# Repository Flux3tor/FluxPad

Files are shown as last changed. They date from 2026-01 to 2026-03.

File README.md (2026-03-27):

# FluxPad

FluxPad is a custom 12-key macropad powered by the Seeed XIAO RP2040.  
It features a rotary encoder for volume and scrolling, an OLED status display, and a compact 3D-printed case designed for daily productivity and creative workflows.

---

## Features
- 12 MX mechanical keys
- Rotary encoder (volume + scroll control)
- 0.91" OLED display (layer & status display)
- Seeed XIAO RP2040 microcontroller
- QMK firmware
- Fully custom 2-layer PCB
- 3D-printed case

---

## Project Images

### Schematic
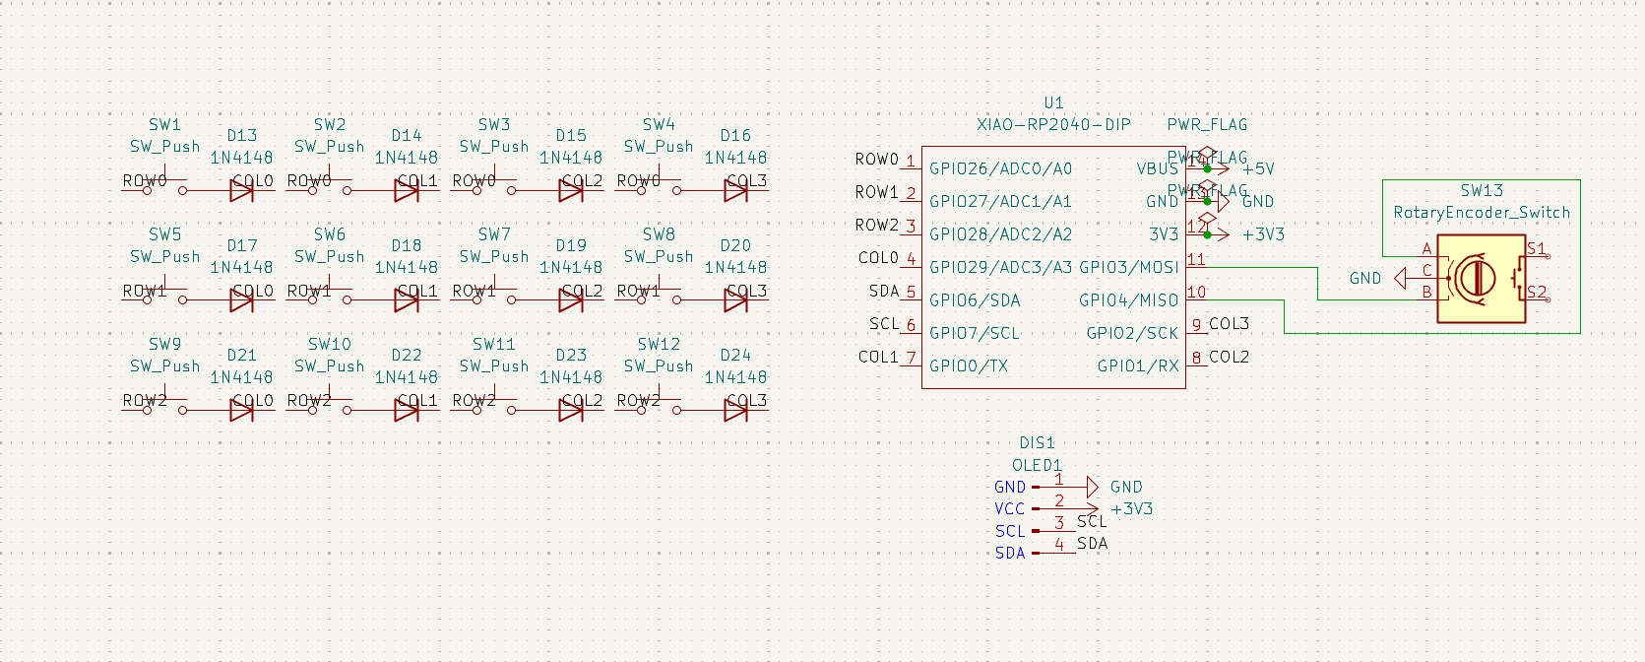
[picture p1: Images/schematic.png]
Schematic


### PCB
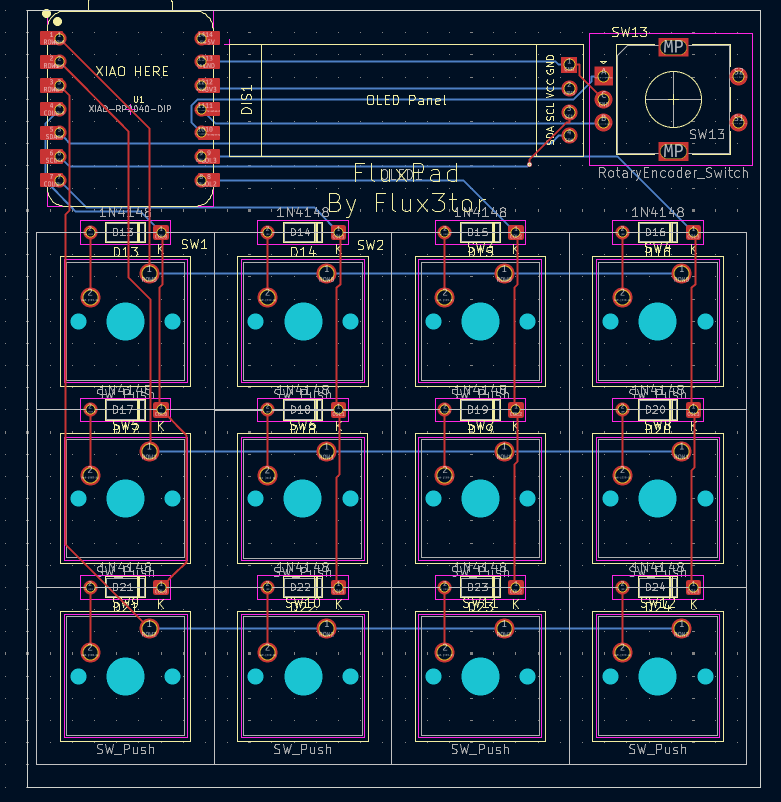
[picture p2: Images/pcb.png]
PCB


### Case Design
#### Bottom Case
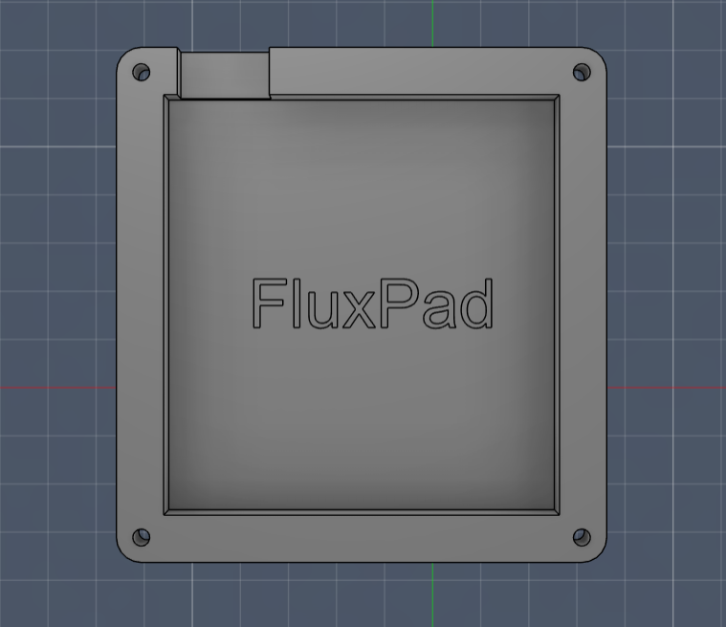
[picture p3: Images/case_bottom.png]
case_bottom


#### Top Case
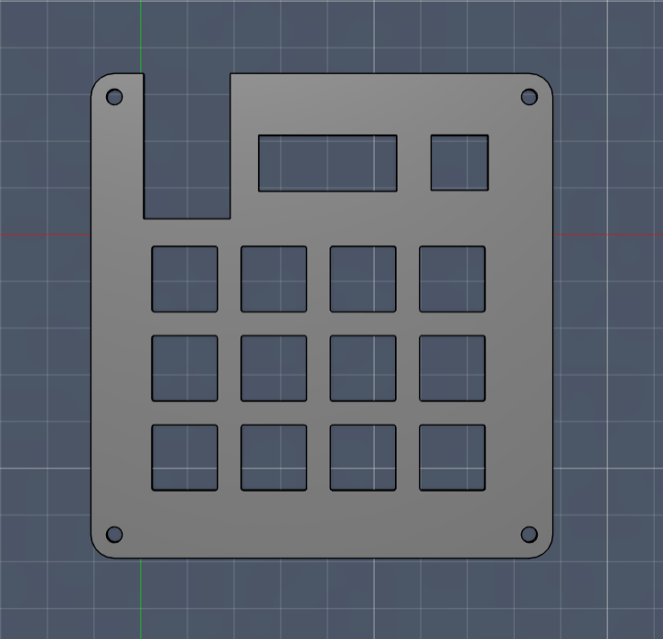
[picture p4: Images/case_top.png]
case_top


### Final Layout
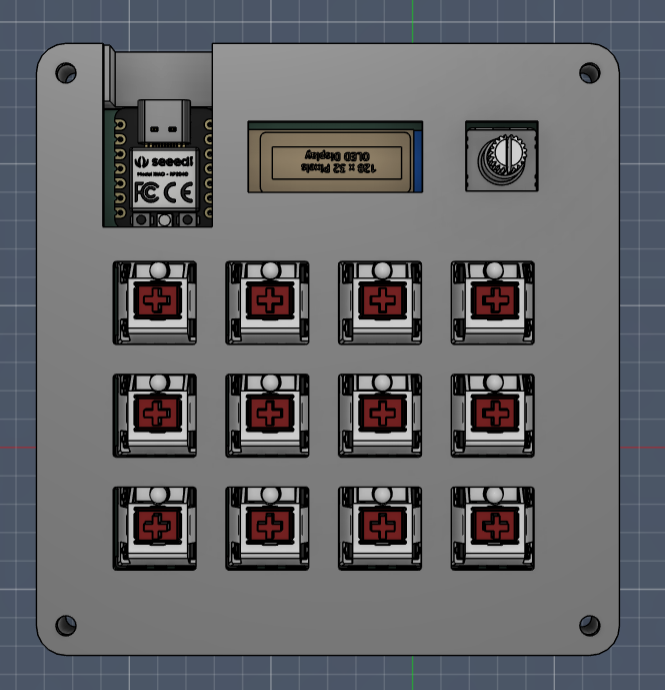
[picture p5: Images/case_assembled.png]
Final


---

## System Overview

### MCU
- Seeed Studio XIAO RP2040 (Through-hole)

### Inputs
- 12x MX mechanical switches
- 1x EC11 rotary encoder

### Output
- 0.91" OLED display (I2C)

---

## Pin Mapping

| Function | GPIO |
|---|---|
| ROW0 | GPIO26 |
| ROW1 | GPIO27 |
| ROW2 | GPIO28 |
| COL0 | GPIO29 |
| COL1 | GPIO0 |
| COL2 | GPIO1 |
| COL3 | GPIO2 |
| Encoder A | GPIO4 |
| Encoder B | GPIO3 |
| OLED SDA | GPIO6 |
| OLED SCL | GPIO7 |

---

## Bill of Materials (BOM)

| Part | Quantity | Manufacturer | Part Number |
|---|---|---|---|
| Seeed XIAO RP2040 (TH) | 1 | Seeed Studio | 102010428 |
| MX Mechanical Switch | 12 | Gateron / Kailh | MX-Style |
| 1N4148 Diodes (TH) | 12 | Vishay | 1N4148 |
| EC11 Rotary Encoder | 1 | ALPS / Generic | EC11 |
| 0.91" OLED Display | 1 | Generic | SSD1306 |
| DSA Keycaps | 12 | Generic | DSA Blank |
| M3x16 Screws | 4 | Generic | M3 |
| Heatset Inserts | 4 | Generic | M3 |

---

## Firmware
FluxPad runs on QMK.  
The firmware supports:
- Key matrix scanning
- OLED display support

Source code is located in the `Firmware/` folder.

---

## Case
The case is fully 3D printed and designed in Fusion360.  
It consists of:
- Bottom shell
- Top plate
- Heatset insert mounts

Exported as three STEP files in the `CAD/` folder.

---

## Build Process

This was my first time soldering, and I ran into a few issues along the way.

While soldering the XIAO RP2040 headers, I accidentally bent the pins without realizing. Instead of redoing everything, I fixed it by using ribbon wires to connect the headers to the PCB. It doesn't look perfect, but it works reliably.

Soldering the full PCB took around 5 hours.

### Firmware Issues

Initially, I used KMK firmware, but it kept crashing when I added OLED support. To debug, I tested the OLED separately using Arduino IDE and confirmed it was working.

I then switched to QMK and rewrote the firmware from scratch, which took another ~5 hours. After that, everything worked properly, including the OLED and encoder.

---

## Final Build

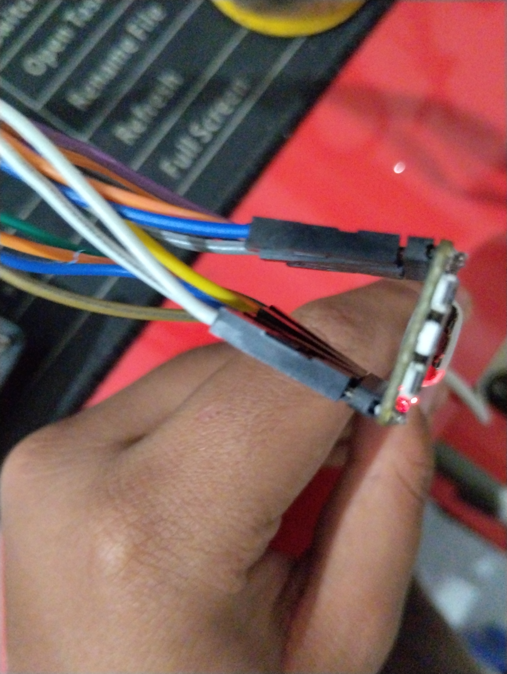
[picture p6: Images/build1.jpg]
Build1
  
Build2

---

## Demo Video

[Watch FluxPad Demo](https://drive.google.com/file/d/1hNpVQt3ci1zXDI4beTaH4Mk9EOGyLXIW/view?usp=drive_link)

---

## Result

The final FluxPad works as intended:
- All 12 keys function correctly  
- Rotary encoder works for control  
- OLED display works  

It may not look perfect due to manual fixes, but it is fully functional and used daily.

---

## Author
Designed and built by **Flux3tor**  
Hack Club Hackpad Project

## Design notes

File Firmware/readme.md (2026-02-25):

# fluxpad

fluxpad

*A short description of the keyboard/project*

* Keyboard Maintainer: [Tushar Sinha](https://github.com/Flux3tor)
* Hardware Supported: *The PCBs, controllers supported*
* Hardware Availability: *Links to where you can find this hardware*

Make example for this keyboard (after setting up your build environment):

    make fluxpad:default

Flashing example for this keyboard:

    make fluxpad:default:flash

See the [build environment setup](https://docs.qmk.fm/#/getting_started_build_tools) and the [make instructions](https://docs.qmk.fm/#/getting_started_make_guide) for more information. Brand new to QMK? Start with our [Complete Newbs Guide](https://docs.qmk.fm/#/newbs).

## Bootloader

Enter the bootloader in 3 ways:

* **Bootmagic reset**: Hold down the key at (0,0) in the matrix (usually the top left key or Escape) and plug in the keyboard
* **Physical reset button**: Briefly press the button on the back of the PCB - some may have pads you must short instead
* **Keycode in layout**: Press the key mapped to `QK_BOOT` if it is available

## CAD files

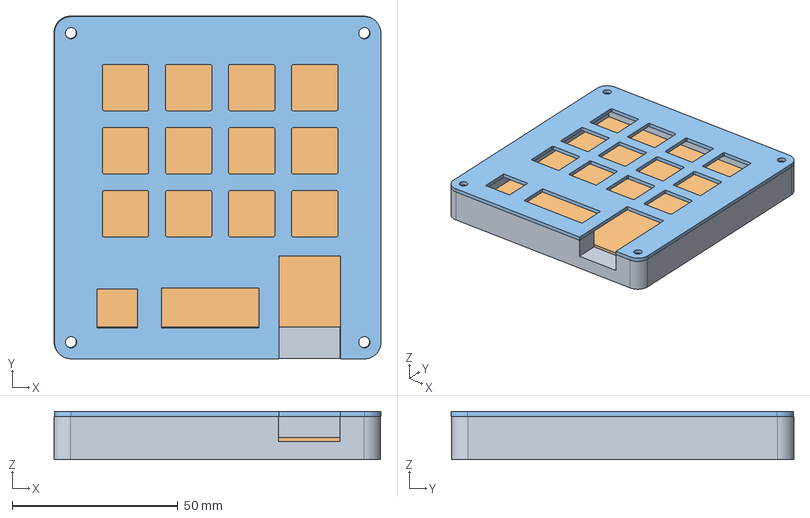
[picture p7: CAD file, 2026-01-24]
CAD/FluxPad Case Assembled.step
98.8 x 103.5 x 14.5 mm

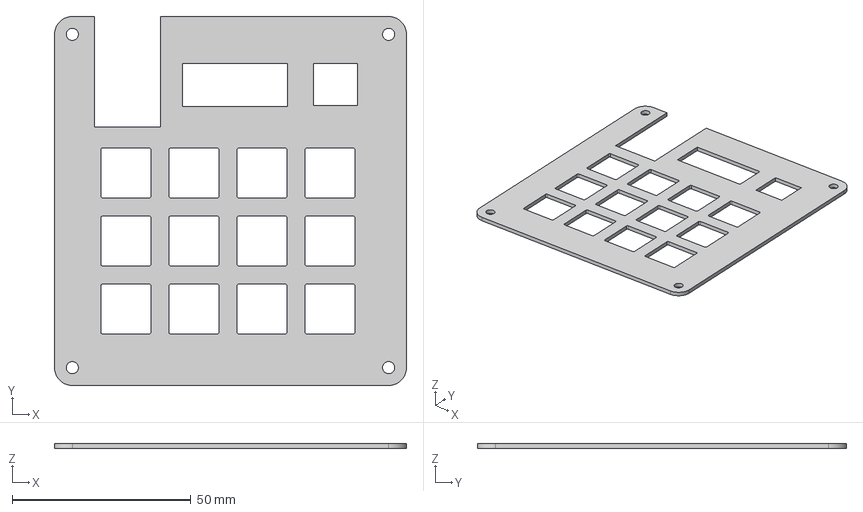
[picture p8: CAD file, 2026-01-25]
CAD/FluxPad Top Case.step
98.6 x 103.3 x 1.50 mm

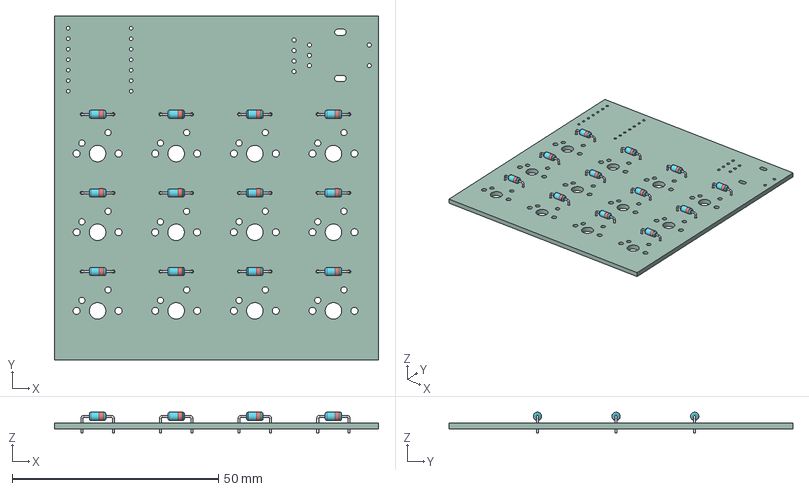
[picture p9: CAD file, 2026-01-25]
PCB/FluxPad.step
78.6 x 83.3 x 5.01 mm
D_DO-35_SOD27_P7.62mm_Horizontal x 12
FluxPad_PCB

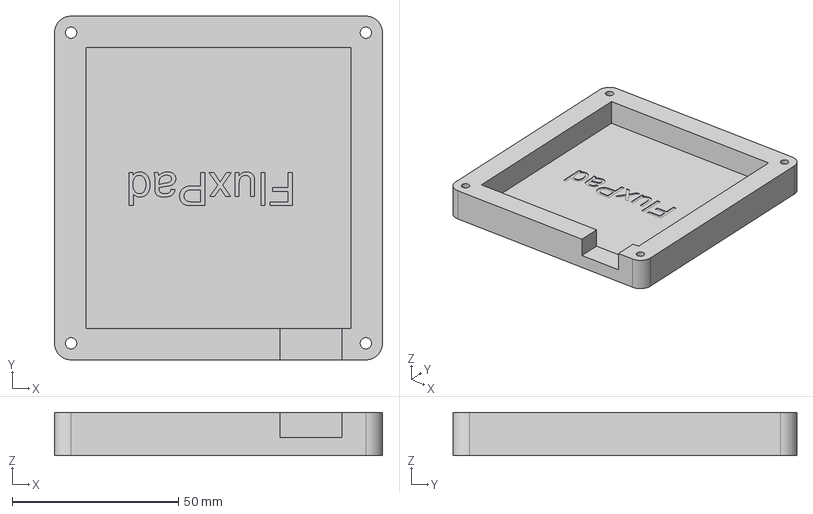
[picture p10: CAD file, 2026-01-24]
CAD/FluxPad Base Case.step
98.6 x 103.3 x 13.0 mm

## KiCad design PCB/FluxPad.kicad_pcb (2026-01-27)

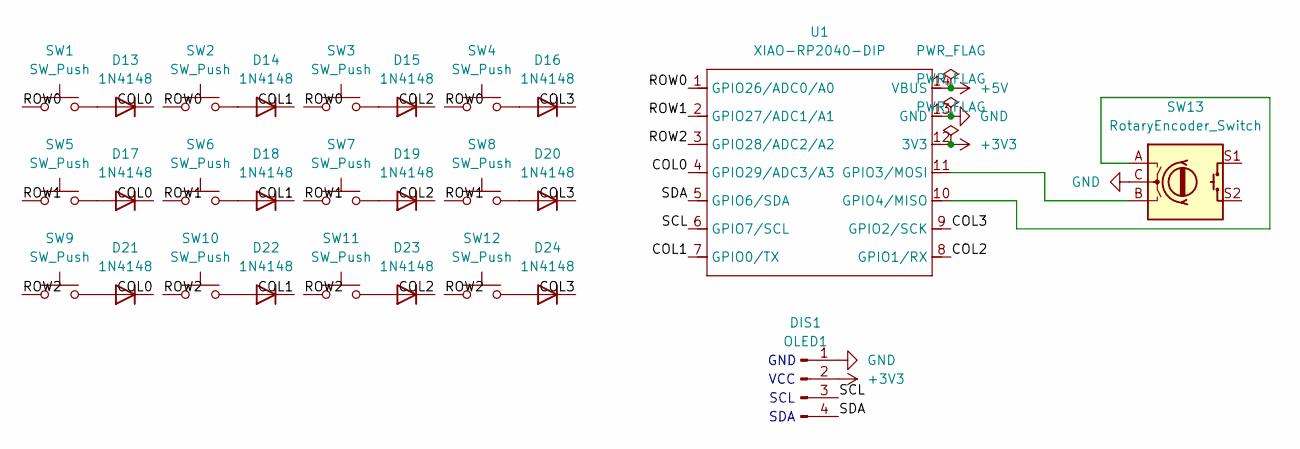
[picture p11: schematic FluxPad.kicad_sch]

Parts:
D13, D14, D15, D16, D17, D18, D19, D20, D21, D22, D23, D24: 1N4148; D_DO-35_SOD27_P7.62mm_Horizontal
DIS1: OLED1; SSD1306-0.91-OLED-4pin-128x32
SW1, SW2, SW3, SW4, SW5, SW6, SW7, SW8, SW9, SW10, SW11, SW12: SW_Push; SW_Cherry_MX_1.00u_PCB
SW13: RotaryEncoder_Switch; RotaryEncoder_Alps_EC11E-Switch_Vertical_H20mm
U1: XIAO-RP2040-DIP

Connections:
+3V3: DIS1.2, U1.12 (3V3)
+5V: U1.14 (VBUS)
/COL0: D13.1 (K), D17.1 (K), D21.1 (K), U1.4 (GPIO29/ADC3/A3)
/COL1: D14.1 (K), D18.1 (K), D22.1 (K), U1.7 (GPIO0/TX)
/COL2: D15.1 (K), D19.1 (K), D23.1 (K), U1.8 (GPIO1/RX)
/COL3: D16.1 (K), D20.1 (K), D24.1 (K), U1.9 (GPIO2/SCK)
/ROW0: SW1.1, SW2.1, SW3.1, SW4.1, U1.1 (GPIO26/ADC0/A0)
/ROW1: SW5.1, SW6.1, SW7.1, SW8.1, U1.2 (GPIO27/ADC1/A1)
/ROW2: SW9.1, SW10.1, SW11.1, SW12.1, U1.3 (GPIO28/ADC2/A2)
/SCL: DIS1.3, U1.6 (GPIO7/SCL)
/SDA: DIS1.4, U1.5 (GPIO6/SDA)
GND: DIS1.1, SW13.C, U1.13 (GND)
unnamed: D13.2 (A), SW1.2
unnamed: D14.2 (A), SW2.2
unnamed: D15.2 (A), SW3.2
unnamed: D16.2 (A), SW4.2
unnamed: D17.2 (A), SW5.2
unnamed: D18.2 (A), SW6.2
unnamed: D19.2 (A), SW7.2
unnamed: D20.2 (A), SW8.2
unnamed: D21.2 (A), SW9.2
unnamed: D22.2 (A), SW10.2
unnamed: D23.2 (A), SW11.2
unnamed: D24.2 (A), SW12.2
unnamed: SW13.B, U1.11 (GPIO3/MOSI)
unnamed: SW13.A, U1.10 (GPIO4/MISO)

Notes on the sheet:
GND
SDA
SCL
VCC

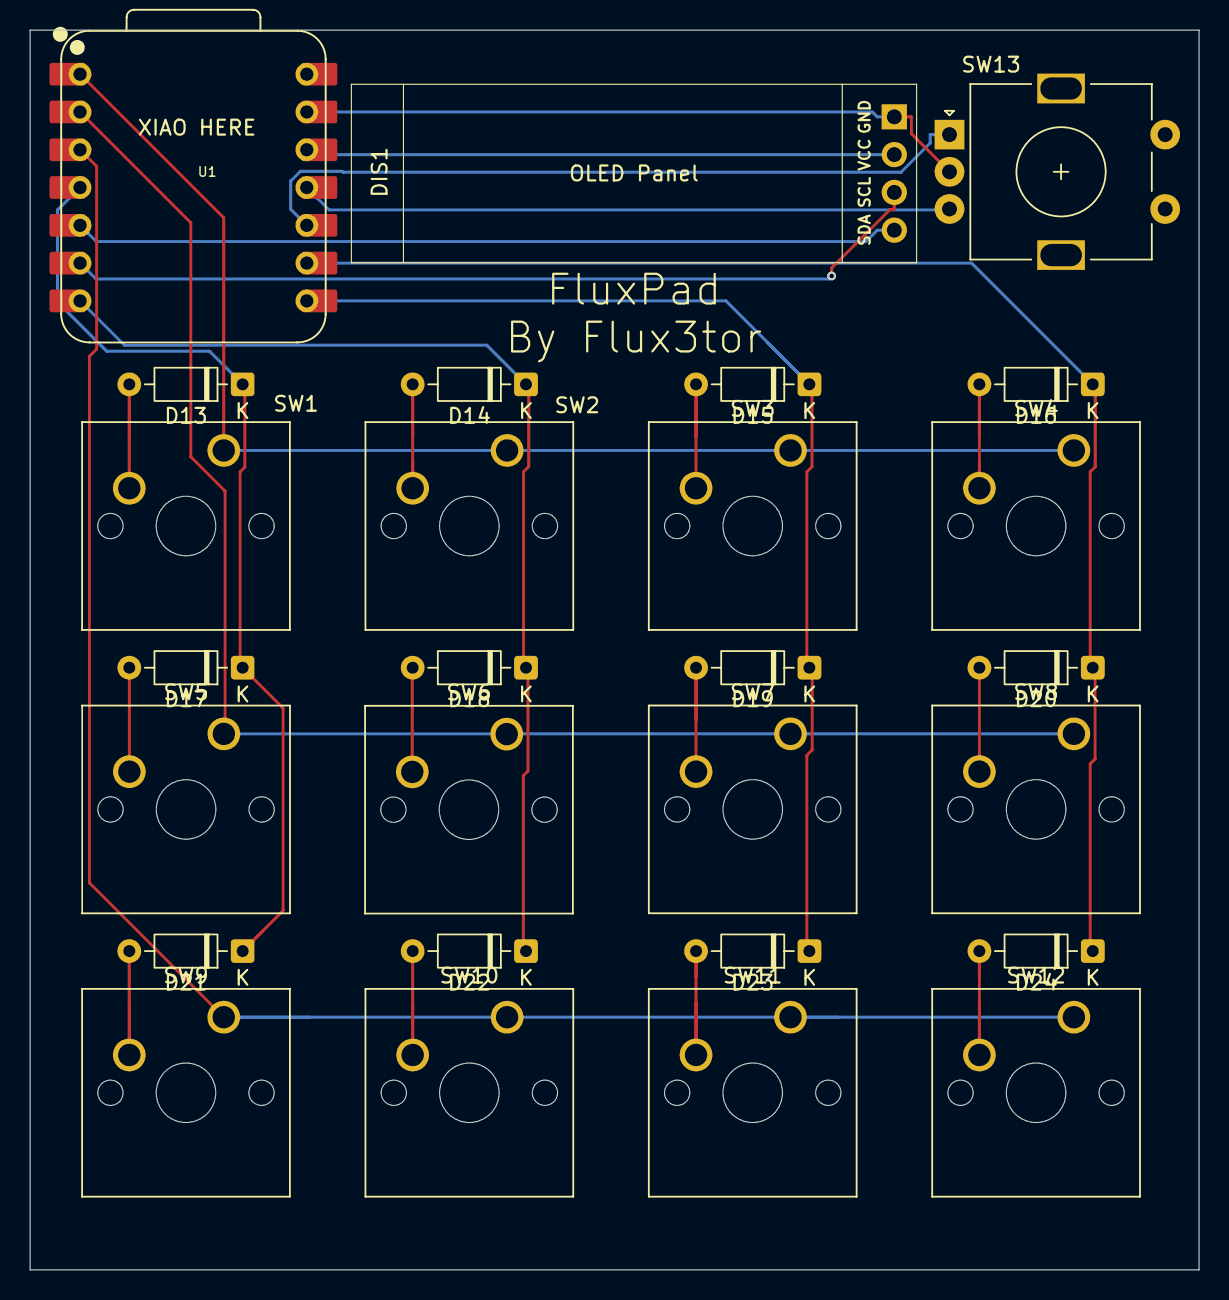
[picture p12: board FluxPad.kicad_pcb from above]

Board: 2 copper layers, 78.6 x 83.3 mm, 27 parts (0 on the bottom side), 25 nets.

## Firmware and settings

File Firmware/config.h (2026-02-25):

#pragma once

#define MATRIX_ROWS 3
#define MATRIX_COLS 4

#define ENCODER_A_PINS { GP4 }
#define ENCODER_B_PINS { GP3 }

#define OLED_DISPLAY_128X32
#define OLED_DISPLAY_ADDRESS 0x3C

#define I2C_DRIVER I2CD1
#define I2C1_SDA_PIN GP6
#define I2C1_SCL_PIN GP7
#define I2C1_CLOCK_SPEED 50000
#define OLED_TIMEOUT 0   // Never turn off

#define RP2040_BOOTLOADER_DOUBLE_TAP_RESET
#define RP2040_BOOTLOADER_DOUBLE_TAP_RESET_TIMEOUT 500U

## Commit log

2026-01-25 Fixed Some Misalignments
    [FluxPad-B_Cu.gbr, FluxPad-B_Mask.gbr, FluxPad-B_Paste.gbr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]
2026-01-27 Added Gerber Files
    [FluxPad-B_Cu.gbr, FluxPad-B_Mask.gbr, FluxPad-B_Paste.gbr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]
2026-02-25 Switched to QMK because KMK doesnt like me
    [FluxPad.kicad_pcb]
